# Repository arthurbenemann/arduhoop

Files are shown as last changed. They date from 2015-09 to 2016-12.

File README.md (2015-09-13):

arduhoop-color-small

An open-source, programmable LED hoop

--

**Currently in progress...**



##Materials

- [4m addressable LED strip](http://www.amazon.com/gp/product/B00LUAKB62?psc=1&ref_=redir_mobile_desktop&ref_=ya_aw_oh_pii) 
- [batteries](http://www.amazon.com/gp/product/B003U7SUUM?psc=1&ref_=redir_mobile_desktop&ref_=ya_aw_oh_pii)
- [Arduino](http://www.amazon.com/gp/product/B004G53J5I?psc=1&ref_=redir_mobile_desktop&ref_=ya_aw_oh_pii)
- [charger board](http://www.amazon.com/gp/product/B00E39RGME?psc=1&ref_=redir_mobile_desktop&ref_=ya_aw_oh_pii)
- [tubing](http://www.mcmaster.com/#50375k58/=yvuo07)
- glue
- XT60 connectors

##Goals

- Double rainbow
- More LEDs than a standard LED hoop

##Schematic


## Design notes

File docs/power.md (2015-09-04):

## @5V
OFF     - 0.22A
RED     - 3.57A
GREEN   - 3.02A
BLUE    - 2.85A
WHITE   - 4.93A
RAINBOW - 3.04A

## @3.7V
OFF     - 0.17A
RED     - 2.32A
GREEN   - 1.57A
BLUE    - 1.35A
WHITE   - 2.82A
RAINBOW - 1.72A

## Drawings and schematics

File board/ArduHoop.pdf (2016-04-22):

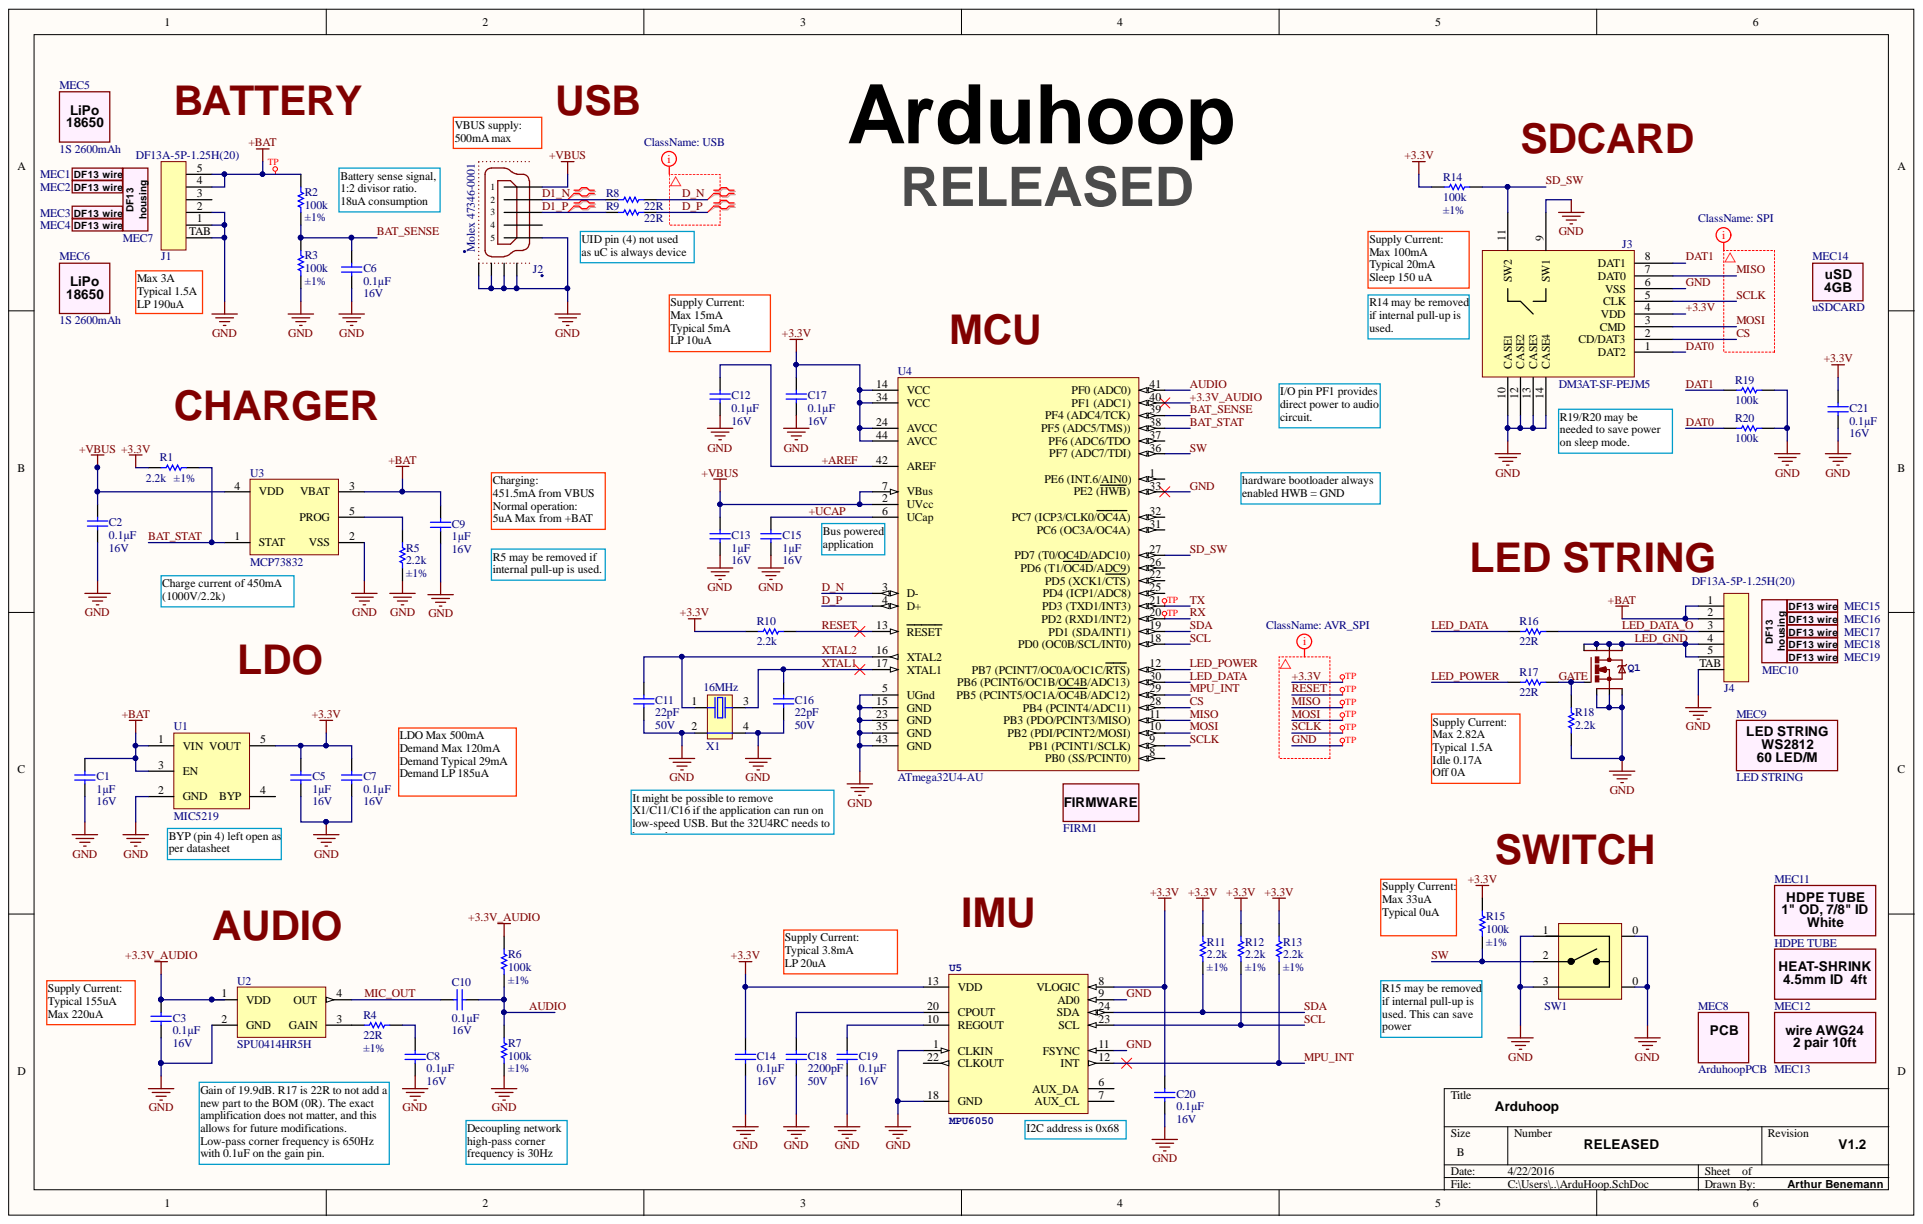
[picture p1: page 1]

UID pin (4) not used
as uC is always device

R14 may be removed
if internal pull-up is
used.

I/O pin PF1 provides
direct power to audio
circuit.

R19/R20 may be
needed to save power
on sleep mode.

R5 may be removed if
internal pull-up is used.

UGnd 5
GND 15

It might be possible to remove
X1/C11/C16 if the application can run on
low-speed USB. But the 32U4RC needs to
be used

MIC5219
BYP (pin 4) left open as
per datasheet
AUDIO

MEC11
HDPE TUBE 1" OD, 7/8" ID White

R15 may be removed
used. This can save
power

Gain of 19.9dB. R17 is 22R to not add a
new part to the BOM (0R). The exact
amplification does not matter, and this
allows for future modifications.
Low-pass corner frequency is 650Hz
with 0.1uF on the gain pin.

Size B | Number RELEASED | Revision V1.2

Date: 4/22/2016 | Sheet of
File: C:\Users\..\ArduHoop.SchDoc | Drawn By: Arthur Benemann

Quantity | Description | Designator | Footprint | Manufacturer 1 | Manufacturer Part Number 1 | Supplier 1 | Supplier Part Number 1
1 | HDPE TUBE 1" OD, 7/8" ID White 10 ft | MEC11 | | Supplier disabled | Supplier disabled | McMaster | 50375K58
1 | HEAT-SHRINK 3/16" ID Before, 3/32" ID After, 4' Length | MEC12 | | Supplier disabled | Supplier disabled | McMaster | 7856K14
1 | WIRE AWG24 2 conductors | MEC13 | | Supplier disabled | Supplier disabled | McMaster | 9697T1
1 | | J2 | Molex 47346-0001 | Molex, LLC | 473460001 | Digi-Key | WM17141CT-ND
1 | CAP CER 2200PF 50V X7R 0603 | C18 | C0603 | Murata Electronics North America | GRM188R71H222KA01 D | Digi-Key | 490-1500-1-ND
1 | CONN MICRO SD CARD PUSH-PUSH R/A | J3 | USD_DM3AT | Hirose Electric Co Ltd | DM3AT-SF-PEJM5 | Digi-Key | HR1964CT-ND
1 | CRYSTAL 16.0000MHZ 18PF SMD | X1 | SMD4_3.2x2.50mm_ABM8 | Abracon LLC | ABM8-16.000MHZ-B2-T | Digi-Key | 535-9134-1-ND
1 | GYRO/ACCELEROMETER 6AXIS 24QFN | U5 | QFN24_4X4X0.9mm | InvenSense | MPU-6050 | Digi-Key | 1428-1007-1-ND
1 | IC LI-ION/LI-POLY CTRLR SOT23-5 | U3 | SOT-23-5 | Microchip Technology | MCP73832T-2ATI/OT | Digi-Key | MCP73832T-2ATI/OTCT-ND
1 | IC MCU 8BIT 32KB FLASH 44TQFP | U4 | ATMEL-TQFP44_ml | Atmel | ATMEGA32U4-AUR | Digi-Key | ATMEGA32U4-AURCT-ND
1 | IC REG LDO 3.3V 0.5A SOT23-5 | U1 | SOT-23-5 | Microchip Technology | MIC5219-3.3YM5-TR | Digi-Key | 576-1281-1-ND
1 | MIC MEMS ANALOG OMNI -22DB | U2 | SPU0414HR5H | Knowles | SPU0414HR5H-SB-7 | Digi-Key | 423-1134-1-ND
1 | MOSFET P-CH 30V 5.8A 8-SOIC | Q1 | SO-8 | Infineon Technologies Americas Corp. | IRF7406TRPBF | Digi-Key | IRF7406PBFCT-ND
1 | SWITCH TACTILE SPST-NO 0.02A 15V | SW1 | EVPAEJB2A | Panasonic Electronic Components | EVP-AEJB2A | Digi-key | P17697CT-ND
12 | CAP CER 0.1UF 16V X7R 0603 | C2, C3, C6, C7, C8, C10, C12, C14, C17, C19, C20, C21 | C0603 | Murata Electronics North America | GRM188R71C104KA01 D | Digi-Key | 490-1532-1-ND
2 | CAP CER 22PF 50V NP0 0603 | C11, C16 | C0603 | Murata Electronics North America | GRM1885C1H220JA01D | Digi-Key | 490-1411-1-ND
2 | CONN HEADER 5POS 1.25MM R/A TIN | J1, J4 | DF13A-5P-1.25H | Hirose Electric Co Ltd | DF13A-5P-1.25H(20) | Digi-Key | H3370-ND
2 | DF13 housing 5pos | MEC7, MEC10 | | Hirose Electric Co Ltd | DF13-5S-1.25C | Digi-Key | H2182-ND
5 | CAP CER 1UF 16V X7R 0603 | C1, C5, C9, C13, C15 | C0603 | Murata Electronics North America | GRM188R71C105KA12 D | Digi-Key | 490-3900-1-ND
5 | RES SMD 22 OHM 1% 1/10W 0603 | R4, R8, R9, R16, R17 | R0603 | Yageo | RC0603FR-0722RL | Digi-Key | 311-22.0HRCT-ND
7 | RES SMD 2.2K OHM 1% 1/10W 0603 | R1, R5, R10, R11, R12, R13, R18 | R0603 | Yageo | RC0603FR-072K2L | Digi-Key | 311-2.20KHRCT-ND
8 | RES SMD 100K OHM 1% 1/10W 0603 | R2, R3, R6, R7, R14, R15, R19, R20 | R0603 | Yageo | RC0603FR-07100KL | Digi-Key | 311-100KHRCT-ND
9 | DF13 pre-crimped 5" wire | MEC1, MEC2, MEC3, MEC4, MEC15, MEC16, MEC17, MEC18, MEC19 | | Hirose Electric Co Ltd | H4BXG-10105-W6 | Digi-Key | H4BXG-10105-W6-ND
1 | LED Strip WS2812B 60 LEDs/meter | MEC9 | | Supplier disabled | Supplier disabled | Amazon | B00LUAKB62
1 | Sandisk 4GB microSDHC Card Class 2 | MEC14 | | Supplier disabled | Supplier disabled | Amazon | B002T8GP8M
2 | Tenergy Li-Ion 18650 3.7V 2600mAh | MEC5, MEC6 | | Supplier disabled | Supplier disabled | Amazon | B003U7SUUM
1 | FIRMWARE | FIRM1
1 | PCB | MEC8

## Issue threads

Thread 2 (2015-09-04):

Need tube hardware

arthurbenemann, 2015-09-04:
Tubes are needed for the hula-hoop:
* [x] spec the tube
* [x] buy the tube

arthurbenemann, 2015-09-04:
Oops, I closed this one by mistake

apaskulin, 2015-09-11:
Purchased High-Pressure/Vacuum Polyethylene Tubing from McMaster-Carr in semi-clear white.
ID: 7/8"
OD: 1"

http://www.mcmaster.com/#50375k58/=yvufw2

This project is in imperial.

Closed 2015-09-11.

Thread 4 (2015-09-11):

Workday: Sunday, Sept 13

apaskulin, 2015-09-11:
Dependent on receiving the tube, Arduhoop workday planned for Sunday!
Location: secret hardware development facility

- [ ] Make a hoop-threading tool
- [ ] Build extension cable for floating battery
- [x] Desolder extra power cables from LED strip
- [ ] Measure and cut tube and LED strip
- [x] FTDI programming design plan
- [x] Find a button
- [ ] Attach floating battery to LED strip
- [ ] Assemble!

@arthurbenemann

apaskulin, 2015-09-13:
Done!

Closed 2015-09-13.

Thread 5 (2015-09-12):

measure battery voltage

arthurbenemann, 2015-09-12:
a hardware pin needs to be added to measure the battery voltage

arthurbenemann, 2015-09-12:
Looks like the 328 in our project has a bandgap reference, so we can measure the battery voltage without any extra wiring.

http://blog.fiftythree.com/posts/measuring-battery-voltage

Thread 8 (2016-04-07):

Add logo to PCB

apaskulin, 2016-04-07:
#7

arthurbenemann, 2016-04-09:
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
lines are to thin right now (68nm), so they will likely not survive the silkscreen process.

@apaskulin can you thicken them?

apaskulin, 2016-04-19:
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
How's this?

arthurbenemann, 2016-04-19:
Looks good
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

Closed 2016-04-19.

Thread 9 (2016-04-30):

pcb rev2 todo

arthurbenemann, 2016-04-30:
#PCB
* modify edges of button so when being routed on mfr. it doesnt come out round
* add fiducials for alignment
usb doesnt sit well because of lip
* ADD PIN1 MARKER TO Q1 SO8

#Bringu-p
* DFU programmer at http://www.atmel.com/tools/flip.aspx
* using firmware at https://github.com/sparkfun/SF32u4_boards/blob/master/sparkfun/avr/bootloaders/caterina/Caterina-promicro16.hex

arthurbenemann, 2016-04-30:
test software attached blinks pin 30 (LED data)

[build9c9ef3bdfe2fccb480bc6e4bac749e41.tmp.zip](https://github.com/arthurbenemann/arduhoop/files/243489/build9c9ef3bdfe2fccb480bc6e4bac749e41.tmp.zip)

arthurbenemann, 2016-04-30:
IMU checked `
Read accel, temp and gyro, error = 0 accel x,y,z: 2172, -308, 15052temperature: 28.271 degrees Celsiusgyro x,y,z : -234, -416, -120, `

arthurbenemann, 2016-05-01:
Programming of Arduino boot-loader done (Caterina). Used and Arduino Uno, with instructions at:
* https://www.arduino.cc/en/Tutorial/ArduinoISP
* http://murchlabs.com/monday-experiment-bootloading-an-atmega32u4-with-arduino/

**ISP pads need better placement since a programmer is required for flashing the bootloader**
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

arthurbenemann, 2016-05-01:
LED power mosfet Q1 looks burned from yesterday tinkering.

arthurbenemann, 2016-05-01:
led connection works. transistor turn-on off of the power needs to be tested still

arthurbenemann, 2016-05-01:
Both switches work

arthurbenemann, 2016-05-01:
SDCard works

arthurbenemann, 2016-05-01:
mic doesn't work. likely damaged during the cleaning process

arthurbenemann, 2016-05-02:
battery charger seems to have been damage when doing the programming.

Battery sense works

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

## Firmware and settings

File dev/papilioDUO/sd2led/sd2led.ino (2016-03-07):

/*
  SD card file dump

 This example shows how to read a file from the SD card using the
 SD library and send it over the serial port.

 The circuit:
 * SD card attached to SPI bus as follows:
 ** MOSI - pin 11
 ** MISO - pin 12
 ** CLK - pin 13
 ** CS - pin 4

 created  22 December 2010
 by Limor Fried
 modified 9 Apr 2012
 by Tom Igoe

 This example code is in the public domain.

 */

#include <SPI.h>
#include <SD.h>
#include <Adafruit_NeoPixel.h>

#define PIXEL_PIN    6    // Digital IO pin connected to the NeoPixels.
#define PIXEL_COUNT 6

#define SD_CS 4

uint8_t sdBuf[512];

Adafruit_NeoPixel strip = Adafruit_NeoPixel(PIXEL_COUNT, PIXEL_PIN, NEO_GRB + NEO_KHZ800);

void setup() {
  // Initialize all pixels to 'off'
  strip.begin();
  strip.show(); 

  
  // Open serial communications and wait for port to open:
  Serial.begin(9600);
  while (!Serial) {
    ; // wait for serial port to connect. Needed for native USB port only
  }


  Serial.print("Initializing SD card...");

  // see if the card is present and can be initialized:
  if (!SD.begin(SD_CS)) {
    Serial.println("Card failed, or not present");
    // don't do anything more:
    return;
  }
  Serial.println("card initialized.");
}

void loop() {

  // open the file. note that only one file can be open at a time,
  // so you have to close this one before opening another.
  File dataFile = SD.open("test.bmp");

  // if the file is available, write to it:
  if (dataFile) {

    while(true){

    if(dataFile.read(sdBuf, 34)             &&    // Load header
      (*(uint16_t *)&sdBuf[ 0] == 0x4D42) &&    // BMP signature
      (*(uint16_t *)&sdBuf[26] == 1)      &&    // Planes: must be 1
      (*(uint16_t *)&sdBuf[28] == 24)     &&    // Bits per pixel: must be 24
      (*(uint32_t *)&sdBuf[30] == 0)) {         // Compression: must be 0 (none)
      
      int   bmpWidth,            // BMP width in pixels
            bmpHeight;           // BMP height in pixels
      uint32_t  bmpImageoffset;  // Start of image data in BMP file
        
      // Supported BMP format -- proceed!
      bmpImageoffset = *(uint32_t *)&sdBuf[10]; // Start of image data
      bmpWidth       = *(uint32_t *)&sdBuf[18]; // Image dimensions
      bmpHeight      = *(uint32_t *)&sdBuf[22];
      // That's some nonportable, endian-dependent code right there.
  
      Serial.print(bmpWidth);
      Serial.write('x');
      Serial.print(bmpHeight);
      Serial.println(F(" pixels"));
      
      dataFile.seek(bmpImageoffset);
  
        int line =0;
      while (dataFile.available()) {
        Serial.print("Line ");
        Serial.print(line++);
        Serial.print("  position ");
        Serial.println(dataFile.position());
        
        dataFile.readBytes(sdBuf, 2 + PIXEL_COUNT*3);
        int i =0;
        for(int pixel = 0; pixel<6; pixel++){
          strip.setPixelColor(pixel, sdBuf[i], sdBuf[i+1], sdBuf[i+2]);
          Serial.print(sdBuf[i],HEX);          
          Serial.print(sdBuf[i],HEX);
          Serial.print(sdBuf[i],HEX);
          Serial.print(' ');
          i += 3;
        }
        Serial.println();
        strip.show();
        delay(200);
      }
     } else{
      Serial.println("incompatible file");
     }
     dataFile.seek(0);
    }
    dataFile.close();
  }
  // if the file isn't open, pop up an error:
  else {
    Serial.println("error opening file.txt");
  }
}

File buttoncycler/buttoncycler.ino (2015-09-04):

// This is a demonstration on how to use an input device to trigger changes on your neo pixels.
// You should wire a momentary push button to connect from ground to a digital IO pin.  When you
// press the button it will change to a new pixel animation.  Note that you need to press the
// button once to start the first animation!

#include <Adafruit_NeoPixel.h>

#define BUTTON_PIN   2    // Digital IO pin connected to the button.  This will be
                          // driven with a pull-up resistor so the switch should
                          // pull the pin to ground momentarily.  On a high -> low
                          // transition the button press logic will execute.

#define PIXEL_PIN    6    // Digital IO pin connected to the NeoPixels.

#define PIXEL_COUNT 240

// Parameter 1 = number of pixels in strip,  neopixel stick has 8
// Parameter 2 = pin number (most are valid)
// Parameter 3 = pixel type flags, add together as needed:
//   NEO_RGB     Pixels are wired for RGB bitstream
//   NEO_GRB     Pixels are wired for GRB bitstream, correct for neopixel stick
//   NEO_KHZ400  400 KHz bitstream (e.g. FLORA pixels)
//   NEO_KHZ800  800 KHz bitstream (e.g. High Density LED strip), correct for neopixel stick
Adafruit_NeoPixel strip = Adafruit_NeoPixel(PIXEL_COUNT, PIXEL_PIN, NEO_GRB + NEO_KHZ800);

bool oldState = HIGH;
int showType = 0;

void setup() {
  pinMode(BUTTON_PIN, INPUT_PULLUP);
  strip.begin();
  strip.show(); // Initialize all pixels to 'off'
}

void loop() {
  // Get current button state.
  bool newState = digitalRead(BUTTON_PIN);

  // Check if state changed from high to low (button press).
  if (newState == LOW && oldState == HIGH) {
    // Short delay to debounce button.
    delay(20);
    // Check if button is still low after debounce.
    newState = digitalRead(BUTTON_PIN);
    if (newState == LOW) {
      showType++;
      if (showType > 7)
        showType=0;
      startShow(showType);
    }
  }

  // Set the last button state to the old state.
  oldState = newState;
}

void startShow(int i) {
  switch(i){
    case 0: colorWipe(strip.Color(0, 0, 0), 5);    // Black/off
            break;
    case 1: colorWipe(strip.Color(255, 0, 0), 5);  // Red
            break;
    case 2: colorWipe(strip.Color(0, 255, 0), 5);  // Green
            break;
    case 3: colorWipe(strip.Color(0, 0, 255), 5);  // Blue
            break;
    case 4: colorWipe(strip.Color(255, 255, 255), 5);  // Blue
            break;
    case 5: rainbow(2);
            break;
    case 6: theaterChaseRainbow(5);
            break;
    case 7: rainbowCycle(1);
            break;
  }
}

// Fill the dots one after the other with a color
void colorWipe(uint32_t c, uint8_t wait) {
  for(uint16_t i=0; i<strip.numPixels(); i++) {
    strip.setPixelColor(i, c);
    strip.show();
    delay(wait);
  }
}

void rainbow(uint8_t wait) {
  uint16_t i, j;

  for(j=0; j<256; j++) {
    for(i=0; i<strip.numPixels(); i++) {
      strip.setPixelColor(i, Wheel((i+j) & 255));
    }
    strip.show();
    delay(wait);
  }
}

// Slightly different, this makes the rainbow equally distributed throughout
void rainbowCycle(uint8_t wait) {
  uint16_t i, j;

  for(j=0; ; j++) { // 5 cycles of all colors on wheel
    for(i=0; i< strip.numPixels(); i++) {
        strip.setPixelColor(i, Wheel(((2 * i * 256 / strip.numPixels()) - j) & 255));
    }
    strip.show();
    delay(wait);
  }
}

void advancedRainbowCycle(uint8_t wait) {
  uint16_t i, j,k;
  uint16_t space=20;

  for(j=0; ; j++) { // 5 cycles of all colors on wheel
    for(i=0; i< strip.numPixels(); i++) {
      if(i>(j+space) || i<j){
        strip.setPixelColor(i, Wheel(((2 * i * 256 / strip.numPixels()) - j) & 255));
      }else{
        strip.setPixelColor(i, 0);  
      }
    }
    strip.show();
    delay(wait);

    space = 20.0*(1.0+sin(k++/60.0))+1;
    if(j>240){
      j=0;
    }
  }
}

//Theatre-style crawling lights.
void theaterChase(uint32_t c, uint8_t wait) {
  for (int j=0; j<10; j++) {  //do 10 cycles of chasing
    for (int q=0; q < 3; q++) {
      for (int i=0; i < strip.numPixels(); i=i+3) {
        strip.setPixelColor(i+q, c);    //turn every third pixel on
      }
      strip.show();

      delay(wait);

      for (int i=0; i < strip.numPixels(); i=i+3) {
        strip.setPixelColor(i+q, 0);        //turn every third pixel off
      }
    }
  }
}

//Theatre-style crawling lights with rainbow effect
void theaterChaseRainbow(uint8_t wait) {
  for (int j=0; j < 256; j++) {     // cycle all 256 colors in the wheel
    for (int q=0; q < 3; q++) {
      for (int i=0; i < strip.numPixels(); i=i+3) {
        strip.setPixelColor(i+q, Wheel( (i+j) % 255));    //turn every third pixel on
      }
      strip.show();

      delay(wait);

      for (int i=0; i < strip.numPixels(); i=i+3) {
        strip.setPixelColor(i+q, 0);        //turn every third pixel off
      }
    }
  }
}

// Input a value 0 to 255 to get a color value.
// The colours are a transition r - g - b - back to r.
uint32_t Wheel(byte WheelPos) {
  WheelPos = 255 - WheelPos;
  if(WheelPos < 85) {
    return strip.Color(255 - WheelPos * 3, 0, WheelPos * 3);
  }
  if(WheelPos < 170) {
    WheelPos -= 85;
    return strip.Color(0, WheelPos * 3, 255 - WheelPos * 3);
  }
  WheelPos -= 170;
  return strip.Color(WheelPos * 3, 255 - WheelPos * 3, 0);
}

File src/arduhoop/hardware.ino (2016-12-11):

#include "arduhoop.h"

const float BATTERY_SCALING = 2.56 * 2.0 / 1023;
const float alpha = 0.01;
float sample_filter = -1;

const int MIC_BIAS = 667;

int readMic() {
  return analogRead(mic_pin) - MIC_BIAS;
}

float batteryVoltage() {
  // read the input on analog pin 0:
  int sample = analogRead(bat_sense);
  if (sample_filter != -1) {
    sample_filter = alpha * sample + (1 - alpha) * sample_filter;
  } else {
    sample_filter = sample;
  }
  return sample_filter * BATTERY_SCALING;
}

bool isBatteryCharging() {
  return digitalRead(bat_stat) == LOW;
}

bool isButtonPressed() {
  return digitalRead(sw) == LOW;
}

bool isSDcardPresent() {
  return digitalRead(sd_sw) == LOW;
}


void ledsOn(){
    if(batteryVoltage() > 3.50){
      digitalWrite(led_pwr, HIGH);
    }else{
      ledsOff();
    }
}

void ledsOff(){
      digitalWrite(led_pwr, LOW);
}

void LedsToggle(){
  if(digitalRead(led_pwr) == HIGH){
      ledsOff();
  }else{
      ledsOn();
  } 
}

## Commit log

2015-09-04 Add sample code from Adafruit
2015-09-04 Initial current measuraments
2015-09-04 reverted back to regular double rainbow
    [buttoncycler.ino]
2015-09-04 Added a schematic drawing
    Close #1
2015-09-04 add schematic file
    [ArduHoop.SchDoc]
2015-09-04 Add photo of prototype
    Closes #2
2015-09-04 removed button code
2015-09-11 Update materials
2015-09-12 update led count for the hoop hardware
2015-09-12 revert to single rainbow
    [arduhoop.ino]
2015-09-13 Added a initial layout for the arduhoop board
    [ArduHoop.PrjPcb, ArduHoop.SchDoc, PCB.PcbDoc]
2015-09-13 added board outline
    [ArduHoop.SchDoc, PCB.PcbDoc]
2016-03-04 Added VHDL code to enable a SDcard passthough on the papilioDUO board
2016-03-07 Add code to read SD card based on arduino template
2016-03-07 Decode "test" Bitmap file and push data in it to a WS2812 LED string
2016-03-08 rename board folder
    [ArduHoop.PrjPcb, ArduHoop.SchDoc, PCB.PcbDoc]
2016-03-08 Replace CPU by Atmega32u4
    [ArduHoop.SchDoc, PCB.PcbDoc]
2016-03-11 add mechanical CAD to test fit of the board in the hoop
    [ArduHoop.SchDoc, PCB.PcbDoc]
2016-03-24 Add extra sensors ( IMU and MIC)
    [ArduHoop.PrjPcb, ArduHoop.SchDoc, PCB.PcbDoc]
2016-04-06 connect modules in schematic
    [ArduHoop.SchDoc, PCB.PcbDoc]
2016-04-06 Add mechanical components to schematic
    [ArduHoop.PrjPcb, ArduHoop.SchDoc, extraComponents.SchLib]
2016-04-06 Rename PCB file
    [ArduHoop.PrjPcb, ArduhoopPCB.PcbDoc, PCB.PcbDoc]
2016-04-06 Clear ERC errors
    [ArduHoop.PrjPcb, ArduHoop.SchDoc, ArduhoopPCB.PcbDoc]
2016-04-07 Documentation Update
    [ArduHoop.SchDoc, ArduhoopPCB.PcbDoc]
2016-04-07 Add mechanical components, update BOM
    [ArduHoop.PrjPcb, ArduHoop.SchDoc, ArduhoopPCB.PcbDoc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]
2016-04-07 Update BOM with supplier data
2016-04-07 Add wiring to BOM
    [ArduHoop.SchDoc, extraComponents.SchLib]
2016-04-07 Add DF13 housing to BOM
    [ArduHoop.SchDoc, extraComponents.SchLib]
2016-04-07 Fix minor schematic issues, release preliminary schematic
    [ArduHoop.PrjPcb, ArduHoop.SchDoc]
2016-04-07 Clear all ERC errors
    [ArduHoop.PrjPcb, ArduHoop.SchDoc]
2016-04-07 Schematic Check
    [ArduHoop.PrjPcb, ArduHoop.SchDoc, ArduhoopPCB.PcbDoc]
2016-04-07 Add schematic PDF
2016-04-08 Finished placement
    [ArduHoop.PrjPcb, ArduHoop.SchDoc, ArduhoopPCB.PcbDoc]
2016-04-08 Preliminary Routing
    [ArduHoop.PrjPcb, ArduHoop.SchDoc, ArduhoopPCB.PcbDoc]
2016-04-08 finished routing, added silk and testpoints
    [ArduHoop.PrjPcb, ArduHoop.SchDoc, ArduhoopPCB.PcbDoc]
2016-04-19 Add logo, rounded signal traces
    [ArduHoop.PrjPcb, ArduhoopPCB.PcbDoc]
2016-04-19 PCB checked
    [ArduHoop.PrjPcb, ArduHoop.SchDoc, ArduhoopPCB.PcbDoc]
2016-04-19 Replace altium plane layer by polygon
    [ArduhoopPCB.PcbDoc]
2016-04-19 Add a outjob for generating GERBERs
    [ArduHoop.PrjPcb]
2016-04-19 REV1.2 - remove paste opening on test-pads
    [ArduHoop.PrjPcb, ArduHoop.SchDoc, ArduhoopPCB.PcbDoc]
2016-04-22 Add BOM to fab outputs
    [ArduHoop.PrjPcb]
2016-05-02 Update source code for board REV1.1
2016-05-07 Fix led_pwr and bat__stat
    [arduhoop.h, hardware.ino, setup.ino]
2016-05-07 add extra led functions
2016-12-11 Add code to turn leds on and off
2016-12-11 Avoid battery over-discharge
